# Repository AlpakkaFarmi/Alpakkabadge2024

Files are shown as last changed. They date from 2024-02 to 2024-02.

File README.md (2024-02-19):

# Alpakkabadge2024

Alpakkabadge2024 - Created originally for Disobey 2024


Schematic: https://github.com/AlpakkaFarmi/Alpakkabadge2024/blob/main/hw/alpakkabadge_schematic_v6.pdf

Binary: https://github.com/AlpakkaFarmi/Alpakkabadge2024/releases/download/1.0/alpakkabadge.uf2

# Getting Started

## 1. Remove battery power

CR2032 is not powerful enough to feed the Pico and three RGB-LEDs, so it is wiser to power the badge via USB or the dedicated power input pads.

To ensure that the battery is not charged from the external power supply, it is essential to cut the jumper below the battery holder.

## 2. Remove three resistors


There are three resistors located inside the Pico footprint.
The red LEDs are connected to GND via three resistors. These resistors keep the LEDs on when the battery is inserted.

To allow Pico to control these red LEDs, remove these three resistors.

## 3. Solder Pico

Add solder to one corner of the Pico footprint and align Pico with the pads. This way you can still adjust board position by heating the soldered pad.

When Pico is aligned, solder all other pads.

## 4. Program Pico

Connect Pico to computer while holding the BOOTSEL-button.
You should see new mass memory device appearing.

Copy the latest release from this repo to Pico and the badge should reboot with blinking lights.

# Building Firmware

## Development prerequisites

Install Rust https://www.rust-lang.org/

## Build

Connect pico into computer in bootmode and run `run` to build and deploy of the firmware

    cargo run --release

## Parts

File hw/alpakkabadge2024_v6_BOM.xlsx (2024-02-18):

Item | Qty | Reference(s) | Value | Manufacturer | Manufacturer part number | Footprint | Datasheet | DNP
1 | 1 | BT1 | 3034 | Keystone Electronics | 3034 |  | https://www.digikey.fi/en/products/detail/keystone-electronics/3034/4499289
2 | 3 | D1, D2, D3 | XZMDKCBDDG45S-9 | Sunledusa |  |  | https://www.sunledusa.com/products/spec/XZMDKCBDDG45S-9.pdf
3 | 3 | R1, R4, R9 | 130R |  |  | Resistor_SMD:R_0603_1608Metric
4 | 6 | R2, R3, R5, R6, R10, R11 | 33R |  |  | Resistor_SMD:R_0603_1608Metric
5 | 3 | R7, R8, R15 | 60R4 |  |  | Resistor_SMD:R_0603_1608Metric
6 | 1 | U1 | Raspberry Pico | Raspberry | Pico | NOT ASSEMBLED | NOT ASSEMBLED | NOT ASSEMBLED

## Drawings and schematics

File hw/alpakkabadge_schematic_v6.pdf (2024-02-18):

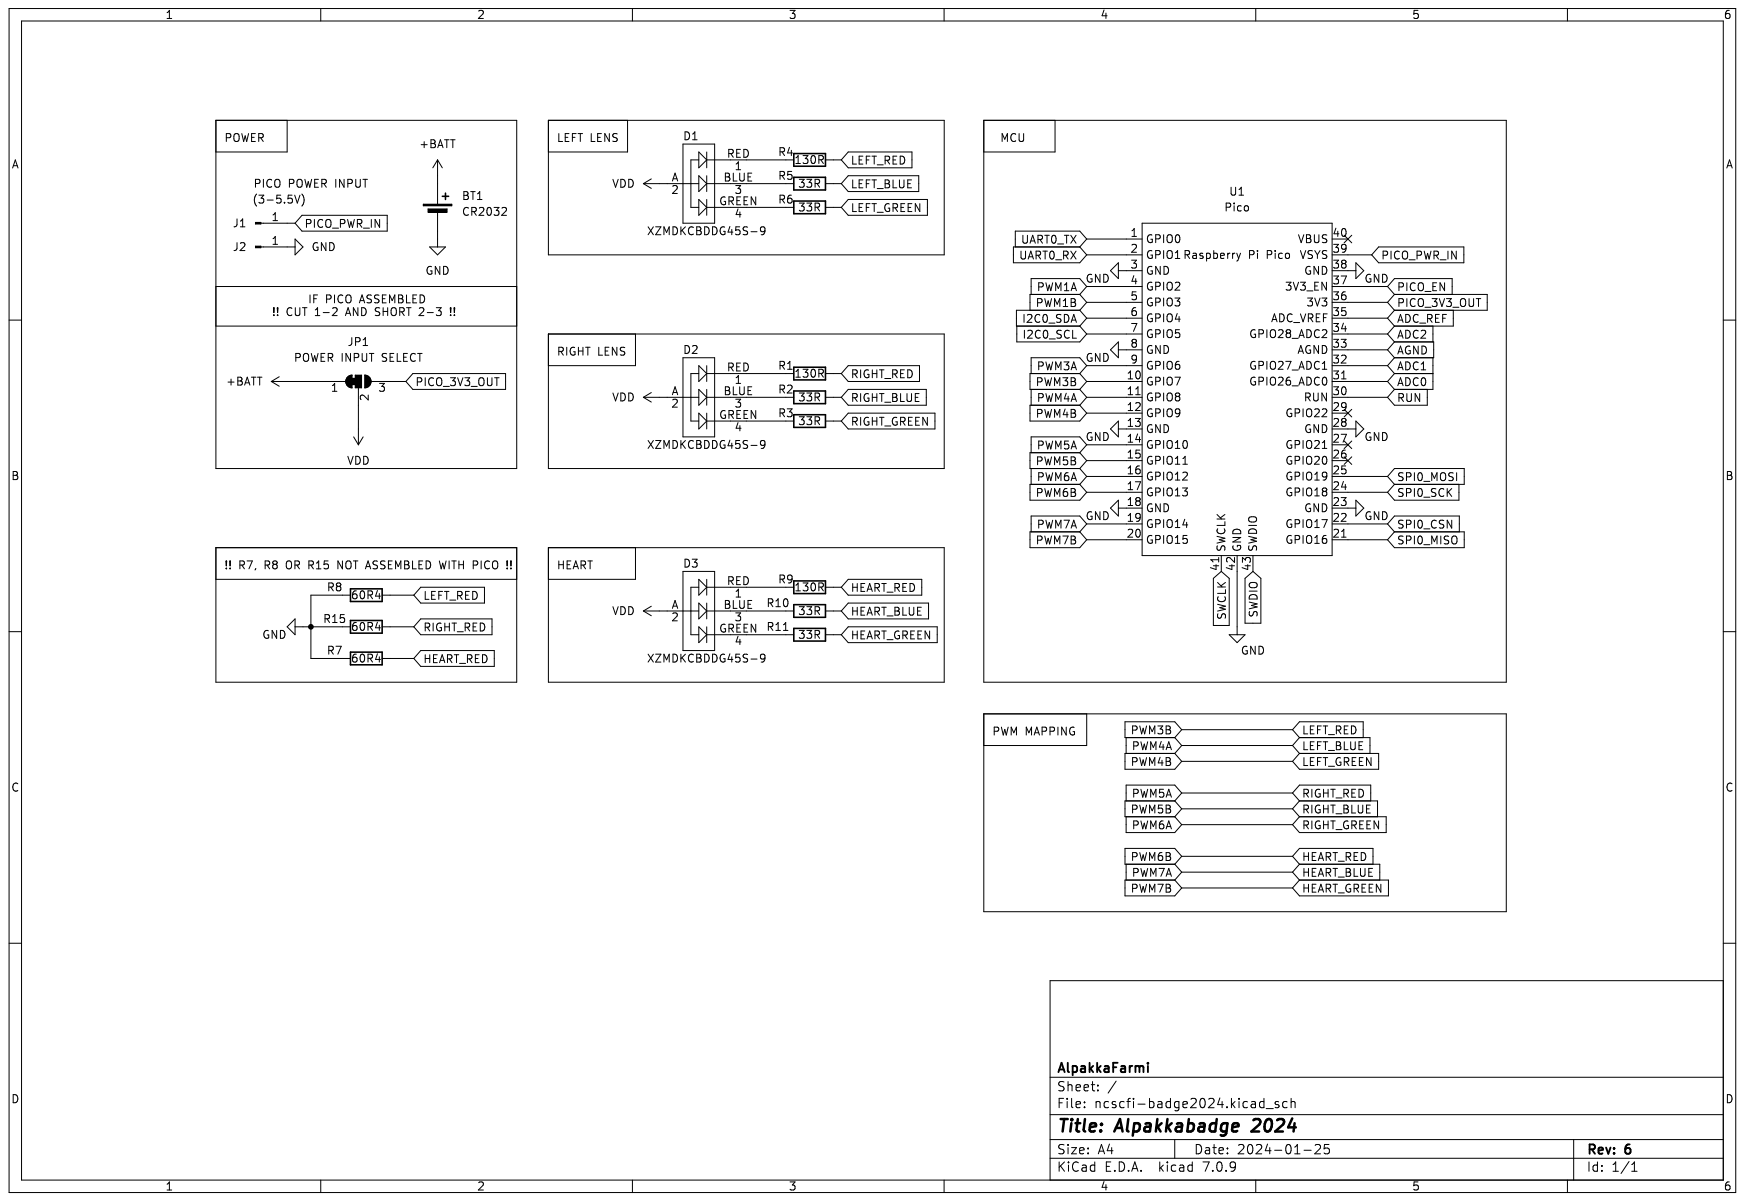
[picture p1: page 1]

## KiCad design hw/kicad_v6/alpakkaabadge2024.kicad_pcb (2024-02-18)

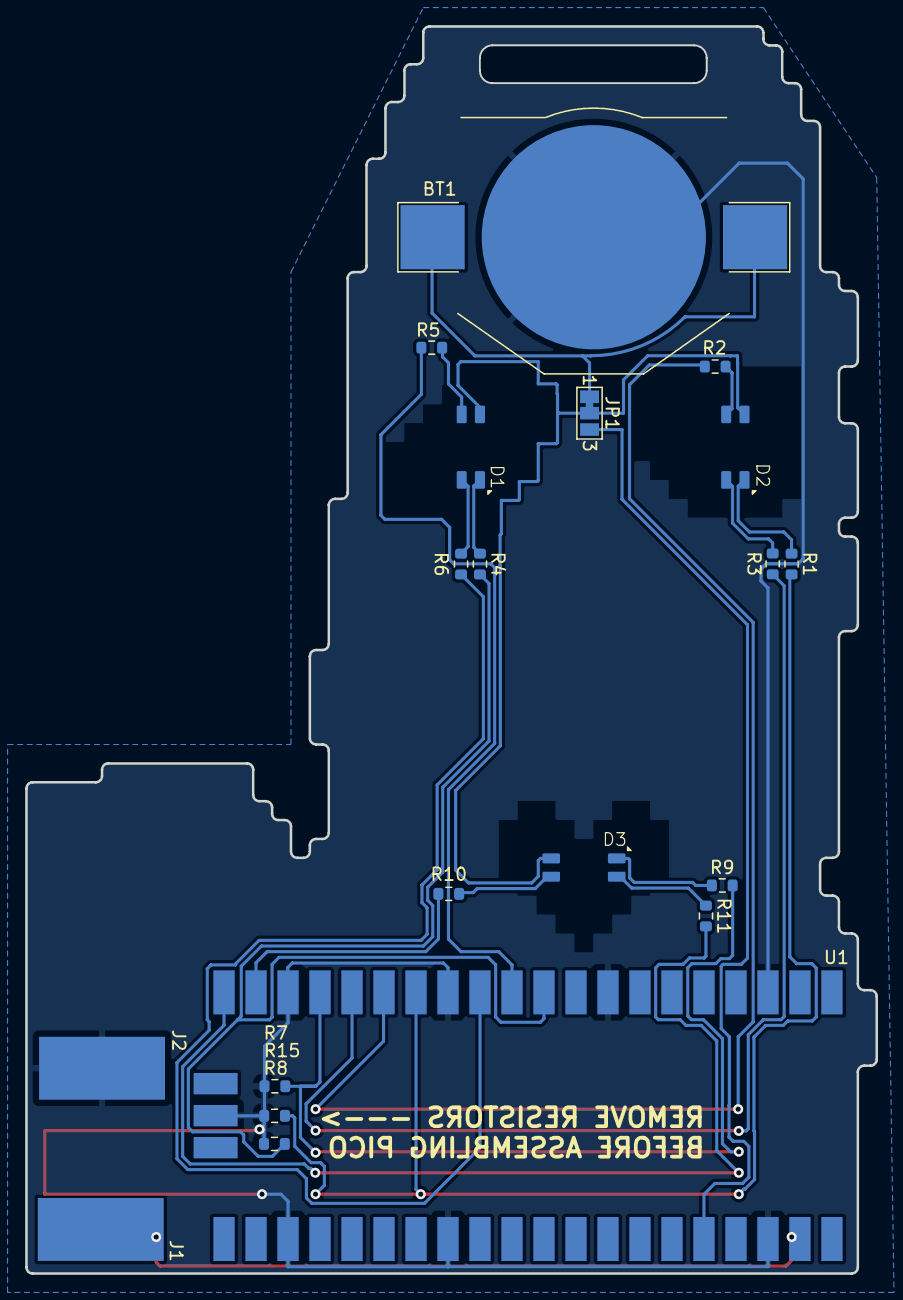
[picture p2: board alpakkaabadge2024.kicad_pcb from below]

Board: 2 copper layers, 67.5 x 99.0 mm, 20 parts (20 on the bottom side), 23 nets.

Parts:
BT1: CR2024; BatteryHolder_Keystone_3002_1x2032
D1, D2, D3: XZMDKCBDDG45S-9; RGB LED
J1: PICO POWER INPUT; SolderWirePad_1x01_SMD_5x10mm
J2: (3-5.5V); SolderWirePad_1x01_SMD_5x10mm
JP1: POWER INPUT SELECT; SolderJumper-3_P1.3mm_Bridged12_Pad1.0x1.5mm_NumberLabels
R1, R4, R9: 140R; R_0603_1608Metric
R2, R3, R5, R6, R10, R11: 30R; R_0603_1608Metric
R7, R8, R15: 60.4; R_0603_1608Metric
U1: Pico; RPi_Pico_SMD_TH

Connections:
+BATT: BT1.1 (+), JP1.1 (A)
GND: BT1.2 (-), J2.1, R7.1, R8.1, R15.1, U1.3 (GND), U1.8 (GND), U1.13 (GND), U1.18 (GND), U1.23 (GND), U1.28 (GND), U1.38 (GND), U1.42 (GND)
HEART_BLUE: R10.2, U1.19 (GPIO14)
HEART_GREEN: R11.2, U1.20 (GPIO15)
HEART_RED: R7.2, R9.2, U1.17 (GPIO13)
LEFT_BLUE: R5.2, U1.11 (GPIO8)
LEFT_GREEN: R6.2, U1.12 (GPIO9)
LEFT_RED: R4.2, R8.2, U1.10 (GPIO7)
unnamed: D1.3 (BLUE), R5.1
unnamed: D1.4 (GREEN), R6.1
unnamed: D1.1 (RED), R4.1
unnamed: D2.3 (BLUE), R2.1
unnamed: D2.4 (GREEN), R3.1
unnamed: D2.1 (RED), R1.1
unnamed: D3.3 (BLUE), R10.1
unnamed: D3.4 (GREEN), R11.1
unnamed: D3.1 (RED), R9.1
PICO_3V3_OUT: JP1.3 (B), U1.36 (3V3)
PICO_PWR_IN: J1.1, U1.39 (VSYS)
PWM5A: R1.2, R15.2, U1.14 (GPIO10)
PWM5B: R2.2, U1.15 (GPIO11)
PWM6A: R3.2, U1.16 (GPIO12)
VDD: D1.2 (A), D2.2 (A), D3.2 (A), JP1.2 (C)

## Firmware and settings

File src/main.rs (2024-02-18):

#![no_std]
#![no_main]
#![warn(clippy::all, clippy::pedantic, clippy::nursery)]

use embedded_hal::watchdog::WatchdogEnable;
use palette::angle::FromAngle;
use panic_halt as _;
//use panic_semihosting as _;

mod bsp;
use bsp::prelude::*;

// Traits
use embedded_hal::digital::v2::{OutputPin, ToggleableOutputPin}; // for pin.toggle()
use embedded_hal::PwmPin;
use hal::clocks::Clock; // for system_clock.freq()

use palette::{FromColor, Hsl, IntoColor, Lch, Srgb, Hsv};

#[entry]
fn main() -> ! {
    let mut pac = pac::Peripherals::take().unwrap();
    let core = pac::CorePeripherals::take().unwrap();

    let mut watchdog = hal::Watchdog::new(pac.WATCHDOG);

    let clocks = hal::clocks::init_clocks_and_plls(
        bsp::XOSC_CRYSTAL_FREQ,
        pac.XOSC,
        pac.CLOCKS,
        pac.PLL_SYS,
        pac.PLL_USB,
        &mut pac.RESETS,
        &mut watchdog,
    )
    .ok()
    .unwrap();

    let mut delay = cortex_m::delay::Delay::new(core.SYST, clocks.system_clock.freq().to_Hz());
    let mut pwm_slices = hal::pwm::Slices::new(pac.PWM, &mut pac.RESETS);

    let sio = hal::Sio::new(pac.SIO);
    let pins = bsp::Pins::new(
        pac.IO_BANK0,
        pac.PADS_BANK0,
        sio.gpio_bank0,
        &mut pac.RESETS,
    );

    let lr: bsp::PWM7 = pins.pwm7.into_mode();
    let lb: bsp::PWM8 = pins.pwm8.into_mode();
    let lg: bsp::PWM9 = pins.pwm9.into_mode();
    let rr: bsp::PWM10 = pins.pwm10.into_mode();
    let rb: bsp::PWM11 = pins.pwm11.into_mode();
    let rg: bsp::PWM12 = pins.pwm12.into_mode();
    let hr: bsp::PWM13 = pins.pwm13.into_mode();
    let hb: bsp::PWM14 = pins.pwm14.into_mode();
    let hg: bsp::PWM15 = pins.pwm15.into_mode();

    let pwm3 = &mut pwm_slices.pwm3;
    pwm3.set_ph_correct();
    pwm3.enable();
    let pwm4 = &mut pwm_slices.pwm4;
    pwm4.set_ph_correct();
    pwm4.enable();
    let pwm5 = &mut pwm_slices.pwm5;
    pwm5.set_ph_correct();
    pwm5.enable();
    let pwm6 = &mut pwm_slices.pwm6;
    pwm6.set_ph_correct();
    pwm6.enable();
    let pwm7 = &mut pwm_slices.pwm7;
    pwm7.set_ph_correct();
    pwm7.enable();

    let plr = &mut pwm3.channel_b;
    plr.set_inverted();
    let plb = &mut pwm4.channel_a;
    plb.set_inverted();
    let plg = &mut pwm4.channel_b;
    plg.set_inverted();
    let prr = &mut pwm5.channel_a;
    prr.set_inverted();
    let prb = &mut pwm5.channel_b;
    prb.set_inverted();
    let prg = &mut pwm6.channel_a;
    prg.set_inverted();
    let phr = &mut pwm6.channel_b;
    phr.set_inverted();
    let phb = &mut pwm7.channel_a;
    phb.set_inverted();
    let phg = &mut pwm7.channel_b;
    phg.set_inverted();

    plr.output_to(lr);
    plr.set_duty(0);
    plb.output_to(lb);
    plb.set_duty(0);
    plg.output_to(lg);
    plg.set_duty(0);
    prr.output_to(rr);
    prr.set_duty(0);
    prb.output_to(rb);
    prb.set_duty(0);
    prg.output_to(rg);
    prg.set_duty(0);
    phr.output_to(hr);
    phr.set_duty(0);
    phb.output_to(hb);
    phb.set_duty(0);
    phg.output_to(hg);
    phg.set_duty(0);

    let mut led: bsp::Led = pins.led.into_mode();
    led.set_low().unwrap();

    let mut heart1 = 0;
    let mut heart2 = 0;
    loop {
        for time in 0u16..65500 {
            let eyes: Srgb = Hsv::new(f32::from(time)/65500.0*360.0*40.0, 1.0, 1.0).into_color();
            let eyes_components = eyes.into_components();
            let eye_r = (eyes_components.0 * 20000.0) as u16;
            let eye_g = (eyes_components.1 * 20000.0) as u16;
            let eye_b = (eyes_components.2 * 65535.0) as u16;
            plr.set_duty(eye_r);
            plg.set_duty(eye_g);
            plb.set_duty(eye_b);
            prr.set_duty(eye_r);
            prg.set_duty(eye_g);
            prb.set_duty(eye_b);

            if time.wrapping_add(20) % 100 == 0 {
                heart1 = 0xffff;
            }
            if time % 100 == 0 {
                heart1 = 0xffff;
                heart2 = 0x1000;
            }

            phr.set_duty(heart1);
            phb.set_duty(heart2);

            heart1 = match heart1.checked_sub(1000) {
                Some(n) => n,
                None => 0,
            };

            heart2 = match heart2.checked_sub(1000) {
                Some(n) => n,
                None => 0,
            };

            delay.delay_ms(10);
        }
    }
}

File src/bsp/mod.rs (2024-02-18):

pub mod prelude;

pub use rp2040_hal as hal;

#[link_section = ".boot2"]
#[no_mangle]
#[used]
pub static BOOT2_FIRMWARE: [u8; 256] = rp2040_boot2::BOOT_LOADER_W25Q080;

hal::bsp_pins!(Gpio25 {
    name: led,
    aliases: { PushPullOutput: Led }
},Gpio7 {
    name: pwm7,
    aliases: { FunctionPwm: PWM7 }
},Gpio8 {
    name: pwm8,
    aliases: { FunctionPwm: PWM8 }
},Gpio9 {
    name: pwm9,
    aliases: { FunctionPwm: PWM9 }
},Gpio10 {
    name: pwm10,
    aliases: { FunctionPwm: PWM10 }
},Gpio11 {
    name: pwm11,
    aliases: { FunctionPwm: PWM11 }
},Gpio12 {
    name: pwm12,
    aliases: { FunctionPwm: PWM12 }
},Gpio13 {
    name: pwm13,
    aliases: { FunctionPwm: PWM13 }
},Gpio14 {
    name: pwm14,
    aliases: { FunctionPwm: PWM14 }
},Gpio15 {
    name: pwm15,
    aliases: { FunctionPwm: PWM15 }
},);

pub const XOSC_CRYSTAL_FREQ: u32 = 12_000_000;

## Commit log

2024-02-18 adding code
    [picoprobe.cfg, rp2040.cfg]
2024-02-18 Added hardware files
    [B_Cu.gbr, B_Mask.gbr, B_Paste.gbr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]
